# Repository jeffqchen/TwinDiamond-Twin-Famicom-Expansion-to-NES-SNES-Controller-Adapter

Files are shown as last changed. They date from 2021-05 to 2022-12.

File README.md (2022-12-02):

# Twin Famicom Expansion A to NES/SNES Controller Adapter

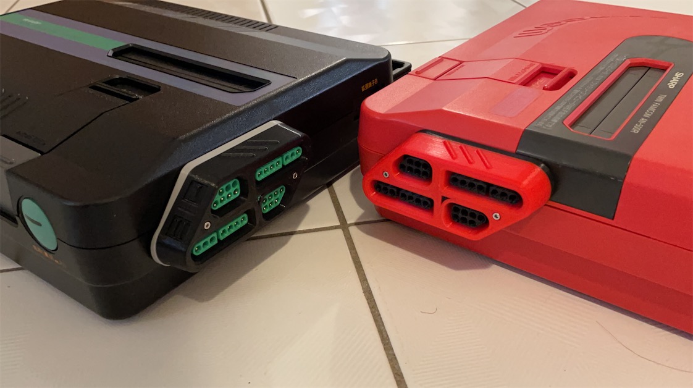
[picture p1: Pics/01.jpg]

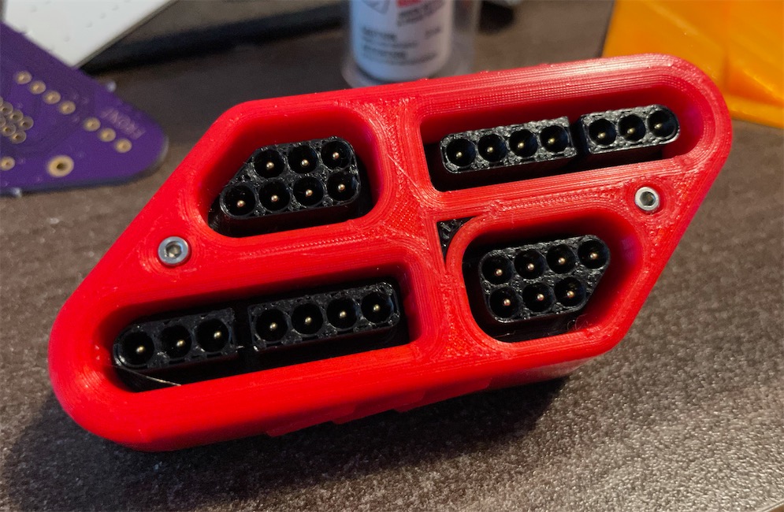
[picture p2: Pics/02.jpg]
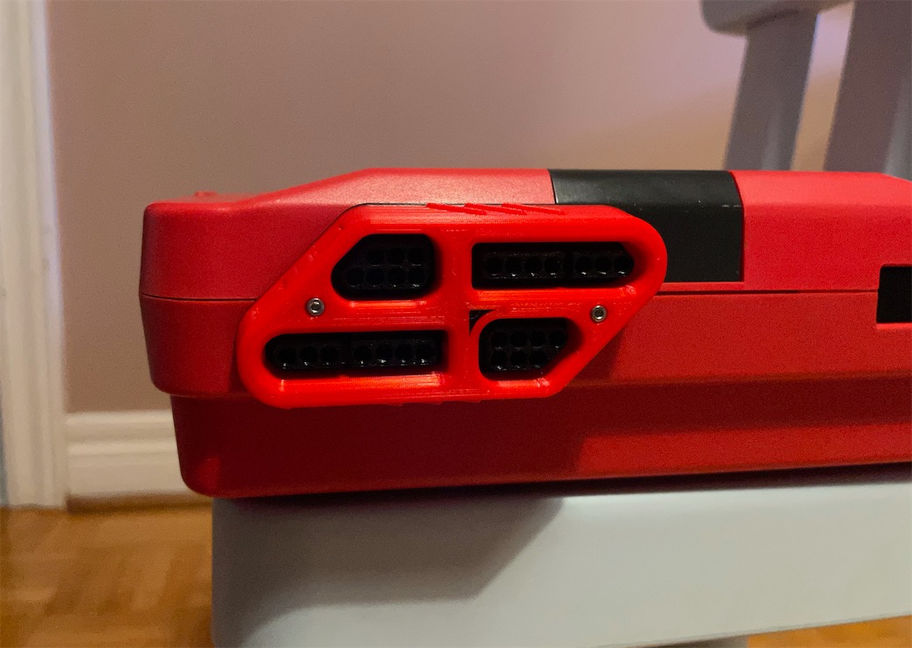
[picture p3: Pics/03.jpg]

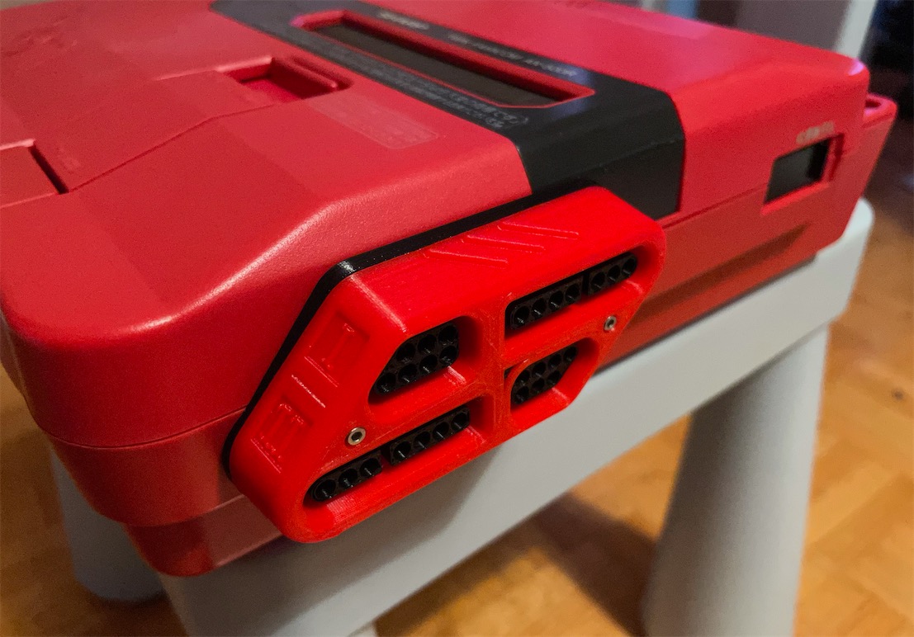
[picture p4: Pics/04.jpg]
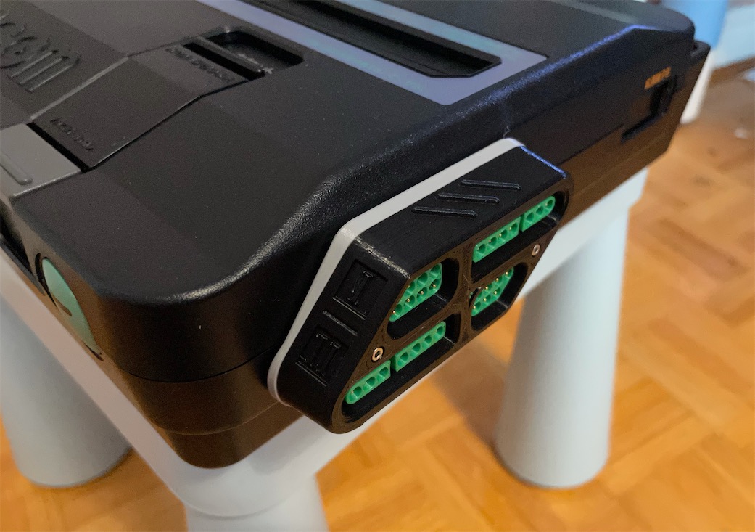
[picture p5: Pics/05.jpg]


This is an adapter for the Nintendo Twin Famicom expansion port A. It is compatible with NES and SNES controllers, plus the NES Zapper lightgun with the 2P NES port.

This adapter also fits well onto the AV Famicom.

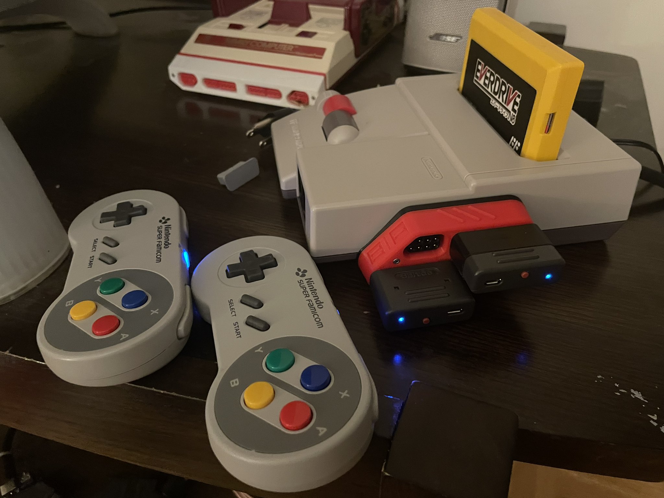
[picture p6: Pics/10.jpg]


## Compatibility Issue

Due to the way different games are coded, [some games](https://github.com/jeffqchen/Famicom-Expansion-Port-Switcher/wiki#significant-titles-affected) can't read the controllers connected on the expansion port (mostly non-Japanese games, designed for the NES).

I have designed an [internal mod](https://github.com/jeffqchen/Famicom-Expansion-Port-Switcher/wiki/Sharp-Twin-Famicom) to deal with this compatibily issue.

-----------

## Parts

- [PCB](https://oshpark.com/shared_projects/1aCic7tG)

- [22x or 28x] Front Pins - Terminal Pins, Male, Machined - [Link](https://github.com/jeffqchen/JeffParts/blob/main/Connectors/Terminal%20Pins/Machined%20Male/info.md)

- [9x] Back Pins - Terminal Pins, Female, Machined - [Link](https://github.com/jeffqchen/JeffParts/blob/main/Connectors/Terminal%20Pins/Machined%20Female/info.md)

- [2x] M2x16mm Hex Screw & Nut - [Link](https://github.com/jeffqchen/JeffParts/blob/main/Parts/M2%20M3%20Hex%20Screw%20%26%20Nut/info.md)

3D Printed Shells

-----------
## Printing

Print everything facing up is a good choice. There really isn't much to it.

The front jacket obviously needs supports.

The plug part might appear split if your line width is set too big. Try 0.35mm and enable "print thin walls" in your slicer. Don't use supports on the the plug. Make sure you don't have too much over-extrusion for the bottom layers as it may clog the holes for the pins. Try an NES plug with the plug part. If they don't go in, clear the NES port holes with a 9/64" drill bit, usually only around the orifice.

The back part doesn't need support either.

-----------
## Assembly

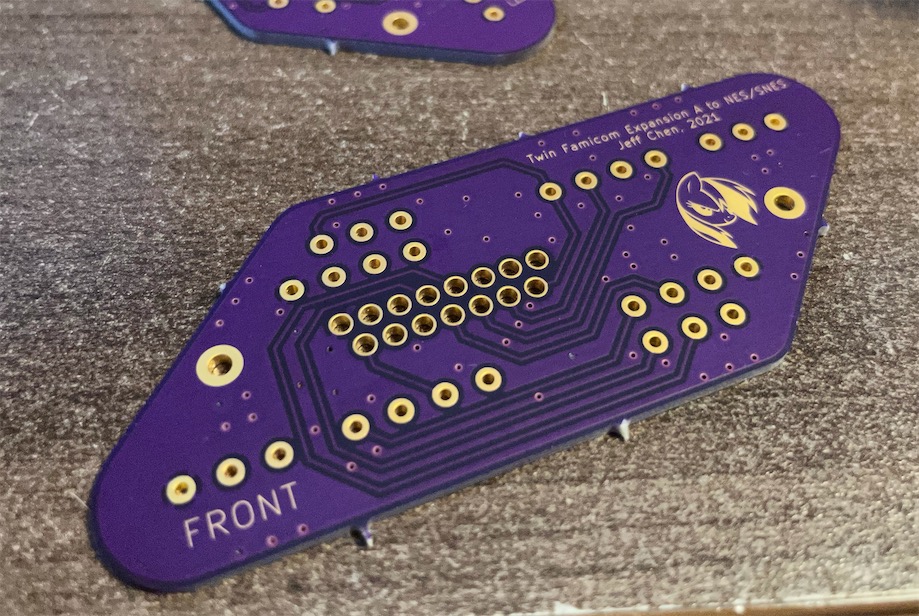
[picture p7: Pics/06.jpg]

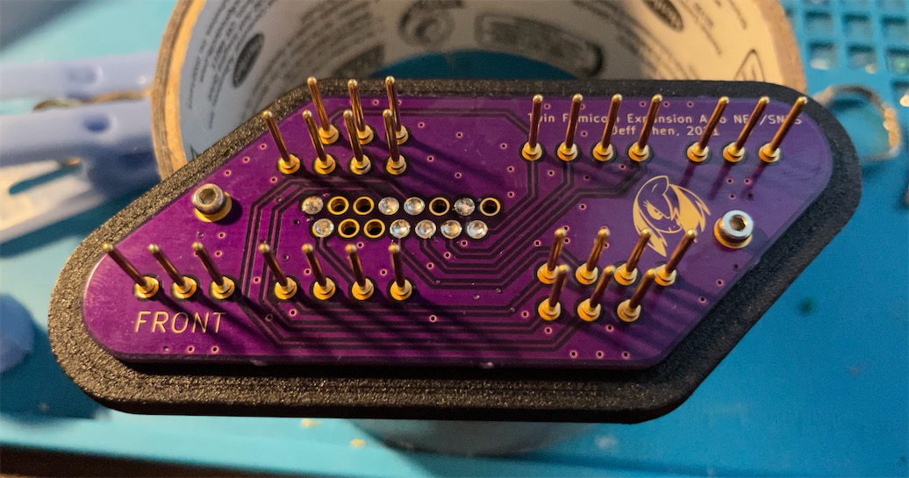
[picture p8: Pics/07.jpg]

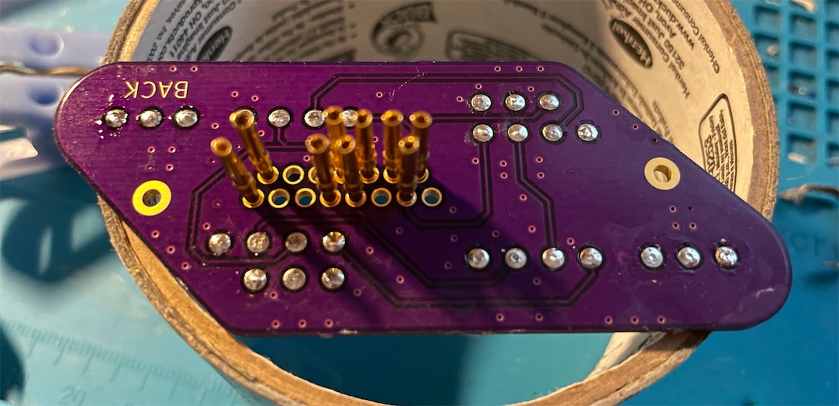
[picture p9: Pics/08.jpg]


Soldering is not too hard but requires attention. You may want to plug in a controller into the printed plug first, insert the pins in from the back of the printed piece, one port at a time, then fit the PCB over the stumps and solder. Use just enough amount of the solder. Make sure nothing protrudes too much up from the surface.

Repeat the same thing for the back female pins. Fit the 9 pins inside the back piece and then solder them in with small amount of solder.

Note you don't have to populate all the pins, but it makes it look better.

Put the plugs part over the front side through the pins, then seat the assembly into the front jacket piece.

Finally, close it up with the back piece and secure with two sets of M2x16mm screws and nuts.

-----------

## Misc
Thingiverse Page:  
- https://www.thingiverse.com/thing:4882800

-----------

## Special Thanks

Chris Kempson:  
- http://chriskempson.com/posts/nes-controller-to-famicom-adapter/

NesDev Wiki:  
- https://wiki.nesdev.com  

Mike Chi (creator of the very famous RetroTink)  
- https://www.retrotink.com

-----------

Shield: [][cc-by-sa]

This work is licensed under a
[Creative Commons Attribution-ShareAlike 4.0 International License][cc-by-sa].

[][cc-by-sa]

[cc-by-sa]: http://creativecommons.org/licenses/by-sa/4.0/
[cc-by-sa-image]: https://licensebuttons.net/l/by-sa/4.0/88x31.png
[cc-by-sa-shield]: https://img.shields.io/badge/License-CC%20BY--SA%204.0-lightgrey.svg

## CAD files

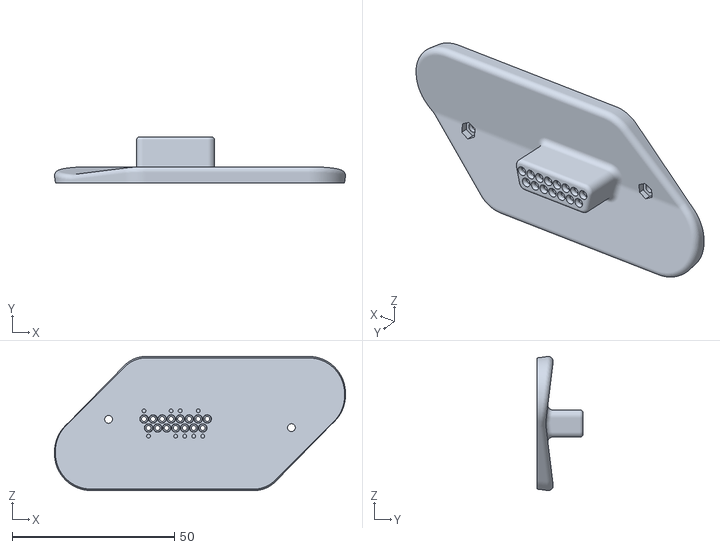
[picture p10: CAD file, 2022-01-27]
3D Print/Back.stl
89.6 x 14.3 x 41.3

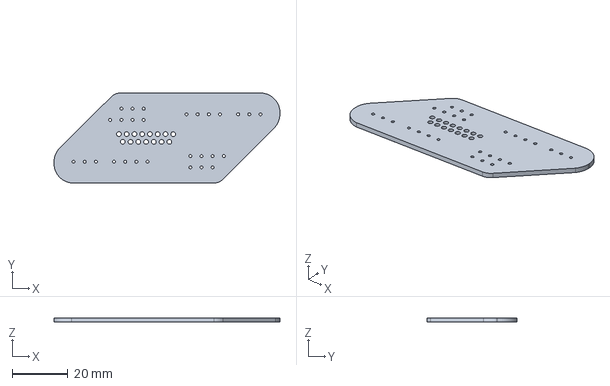
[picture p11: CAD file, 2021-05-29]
KiCAD/TwinFamicom_Expansion.step
81.0 x 32.3 x 1.60 mm

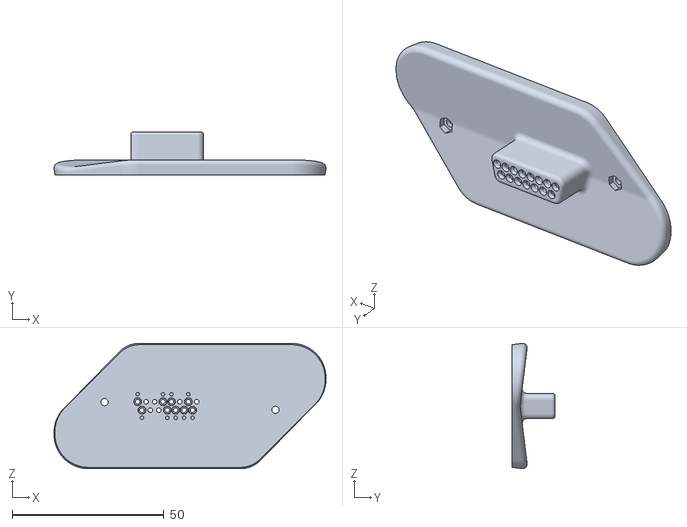
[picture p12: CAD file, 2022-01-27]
3D Print/Back-limited pin.stl
89.6 x 14.3 x 41.3

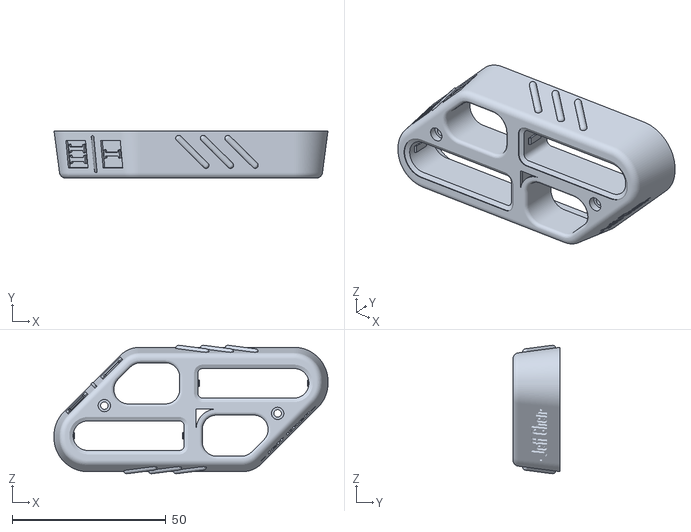
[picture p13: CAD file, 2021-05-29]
3D Print/Front Jacket.stl
89.0 x 15.3 x 41.7

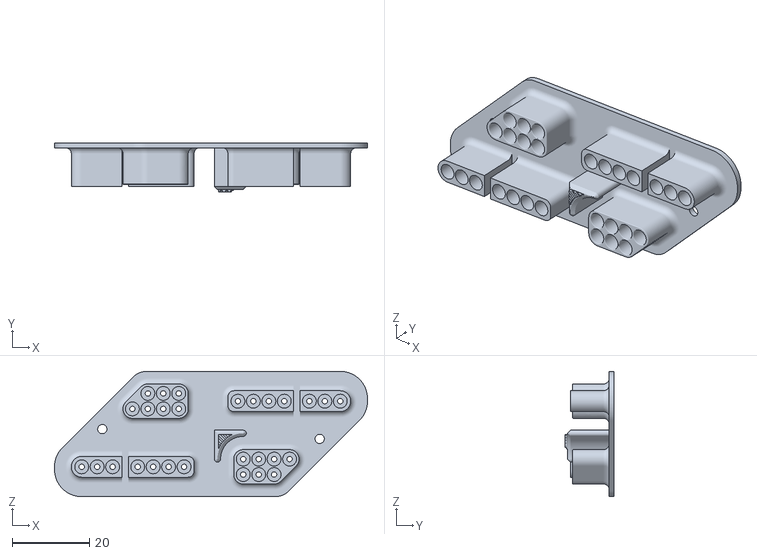
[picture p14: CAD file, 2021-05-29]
3D Print/Plug.stl
81.0 x 12.8 x 32.4

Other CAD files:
3D Print/PCB.stl

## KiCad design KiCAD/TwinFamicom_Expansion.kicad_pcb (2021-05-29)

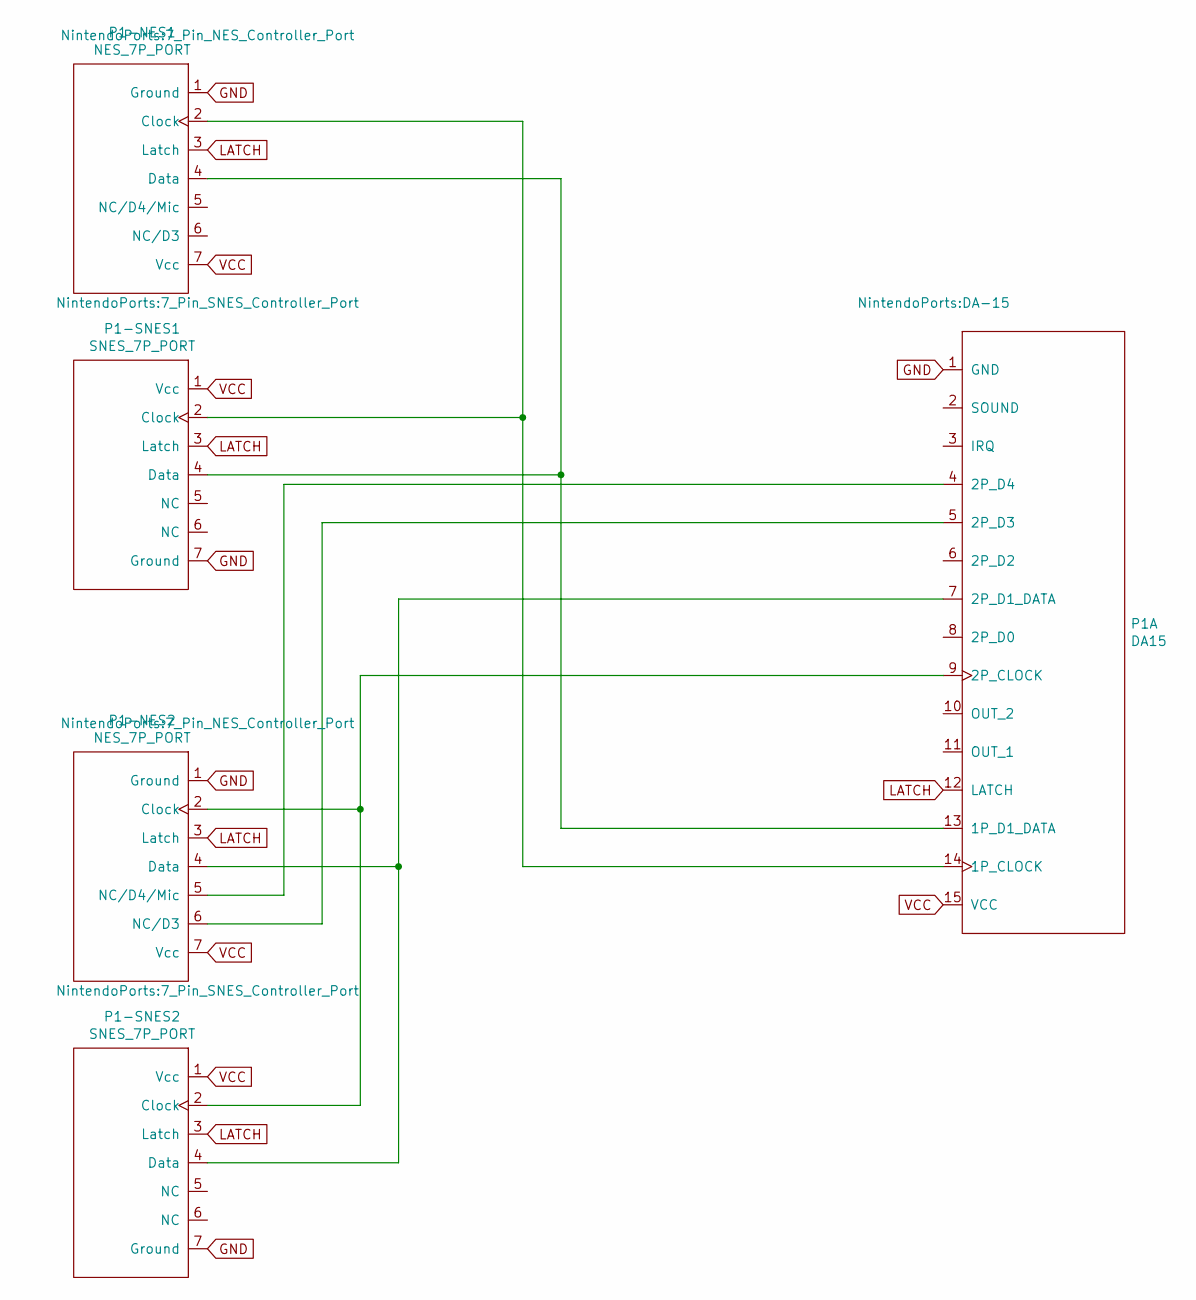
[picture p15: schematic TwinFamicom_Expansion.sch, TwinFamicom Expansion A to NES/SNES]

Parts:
P1: DA15; DA-15
P1-NES1, P1-NES2: NES_7P_PORT; 7_Pin_NES_Controller_Port
P1-SNES1, P1-SNES2: SNES_7P_PORT; 7_Pin_SNES_Controller_Port

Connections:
GND: P1.1 (GND), P1-NES1.1 (Ground), P1-NES2.1 (Ground), P1-SNES1.7 (Ground), P1-SNES2.7 (Ground)
LATCH: P1.12 (LATCH), P1-NES1.3 (Latch), P1-NES2.3 (Latch), P1-SNES1.3 (Latch), P1-SNES2.3 (Latch)
unnamed: P1.14 (1P_CLOCK), P1-NES1.2 (Clock), P1-SNES1.2 (Clock)
unnamed: P1.13 (1P_D1_DATA), P1-NES1.4 (Data), P1-SNES1.4 (Data)
unnamed: P1.9 (2P_CLOCK), P1-NES2.2 (Clock), P1-SNES2.2 (Clock)
unnamed: P1.7 (2P_D1_DATA), P1-NES2.4 (Data), P1-SNES2.4 (Data)
unnamed: P1.4 (2P_D4), P1-NES2.5 (NC/D4/Mic)
unnamed: P1.5 (2P_D3), P1-NES2.6 (NC/D3)
VCC: P1.15 (VCC), P1-NES1.7 (Vcc), P1-NES2.7 (Vcc), P1-SNES1.1 (Vcc), P1-SNES2.1 (Vcc)

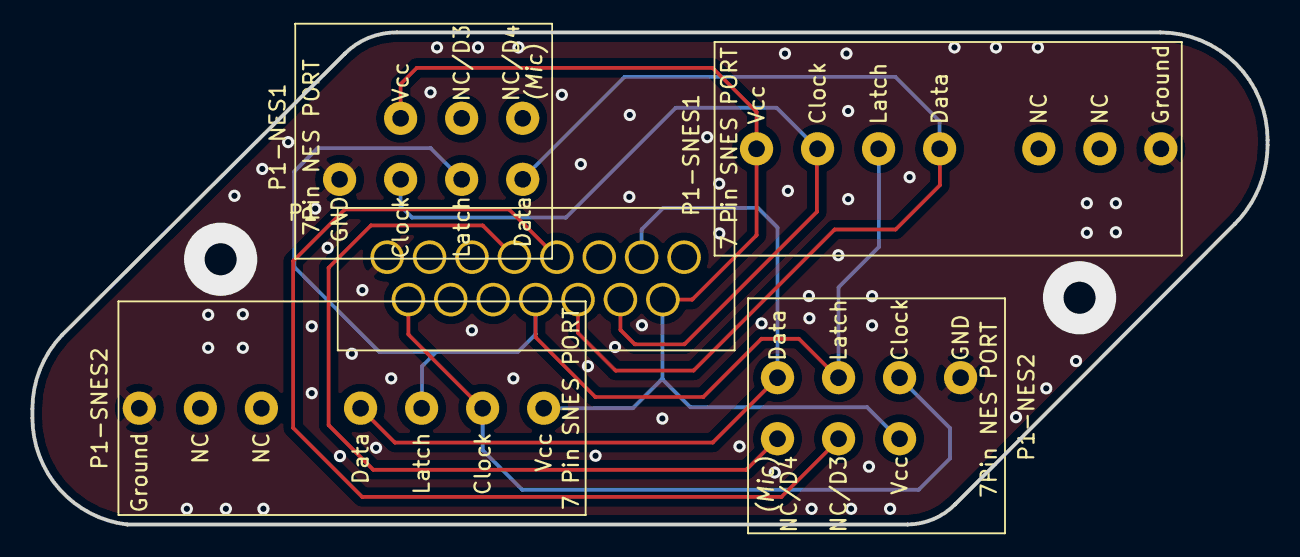
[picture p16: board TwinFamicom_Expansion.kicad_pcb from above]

Board: 2 copper layers, 81.0 x 32.3 mm, 5 parts (0 on the bottom side), 9 nets.

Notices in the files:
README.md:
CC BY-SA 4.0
